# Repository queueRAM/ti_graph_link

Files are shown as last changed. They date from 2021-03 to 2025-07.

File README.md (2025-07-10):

TI-Graph Link adapters
----------------------
This repository contains information about three types of TI-Graph Link adapters:
* [TI-Graph Link serial (gray)](#ti-graph-link-serial-gray)
* [TI-Graph Link serial (black)](#ti-graph-link-serial-black)
* [TI USB Graph Link (silver)](#ti-usb-graph-link-silver)

Building Firmware
-----------------
The included makefile build system can build both the Silver Link "B" and the serial Gray Link firmware. The resulting .eep file should be bit-compatible with the EEPROM contents.

Silver Link build dependencies are:
 * [sdcc](http://sdcc.sourceforge.net): versions 3.8.0 through 4.2.0 have been tested
 * [GNU make](https://www.gnu.org/software/make/)
 * Python 3: for the script which generates the Autoexec header and checksum

Gray Link build dependencies are:
 * [gputils](https://gputils.sourceforge.io/): version 1.5.2 has been tested
 * [GNU make](https://www.gnu.org/software/make/)

```sh
$ make
sdas8051 -lops ti_graph_link_silver.asm
sdcc -mmcs51 --code-size 0x1400 ti_graph_link_silver.rel -o ti_graph_link_silver.hex
makebin -p ti_graph_link_silver.hex ti_graph_link_silver.bin
./tools/generate_eeprom.py ti_graph_link_silver.bin ti_graph_link_silver.eep
gpasm  -o ti_graph_link_serial_gray.hex ti_graph_link_serial_gray.asm
ti_graph_link_silver.bin: OK
ti_graph_link_serial_gray.hex: OK
```

TI-Graph Link serial (gray)
---------------------------
The gray TI-Graph Link cable uses a DB-25 serial connector and works with Windows and Macintosh computers. It includes adapters to connect to DB-9 RS232 serial port on a PC and a DIN adapter to connect to RS-422 serial port on a Mac. [Merthsoft's Link Cables page](http://merthsoft.com/linkguide/cable.html#greytigl) contains additional information about this cable.
TI-Graph Link serial gray
TI-Graph Link serial gray PCB annotated

## Gray Link: Schematic
Full schematic is included in the repository as [TI-Graph Link serial (gray) PDF](schematics/ti_graph_link_serial_gray/ti_graph_link_serial_gray_rev1.pdf) or KiCad.
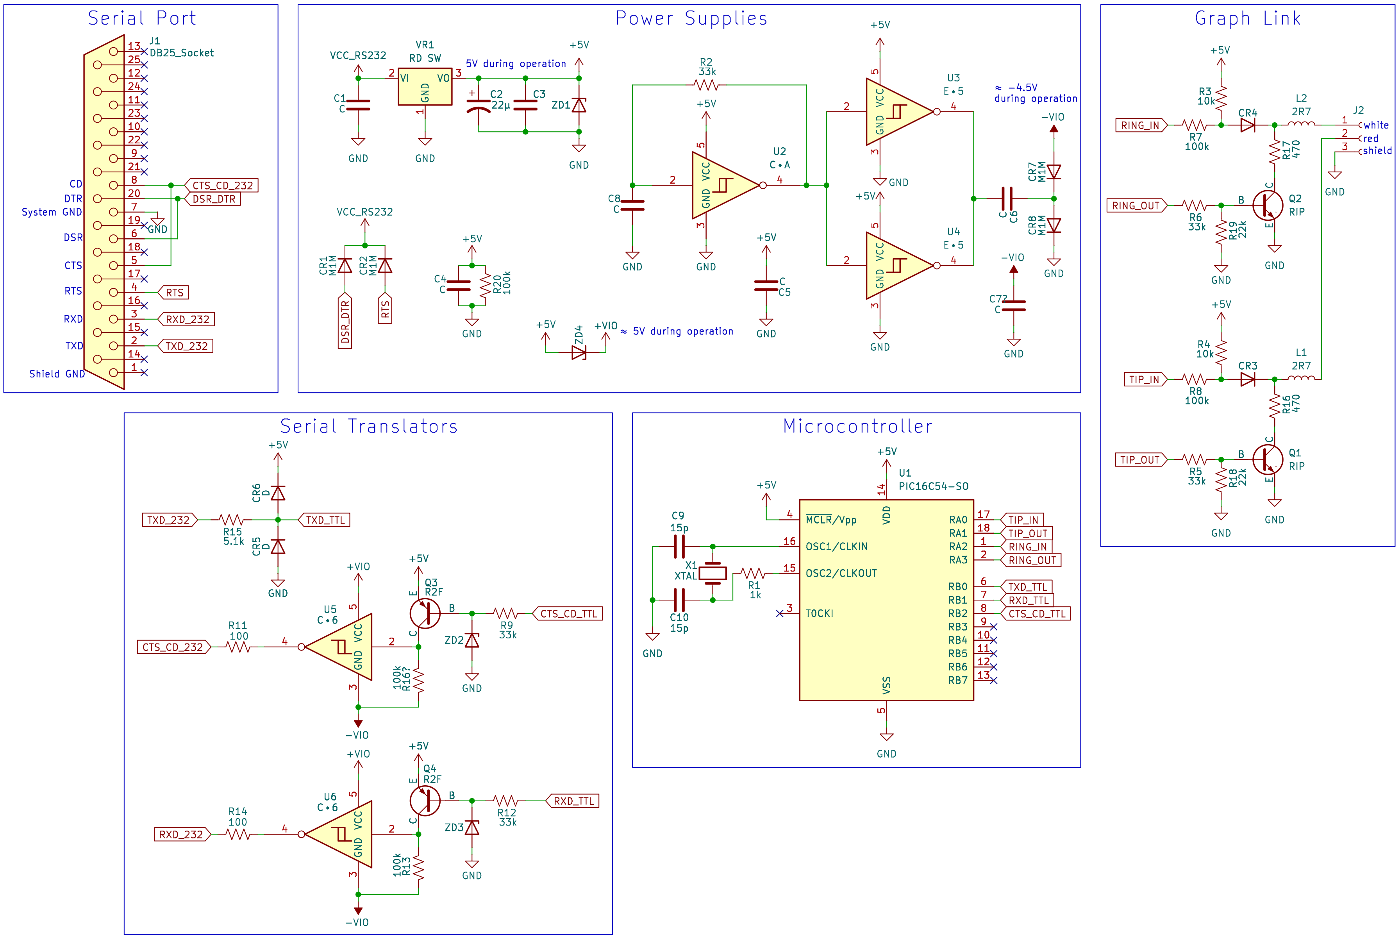
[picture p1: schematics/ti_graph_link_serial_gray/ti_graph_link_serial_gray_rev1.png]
TI-Graph Link serial (gray) Schematic


The control of the cable is provided with a PIC16C54 which receives requests on serial TX, sends responses back on serial RX, and manages the graph link communication on the tip/ring of the 2.5mm cable through two pairs of pins. There are three power supplies on board: 5V regulator for the PIC and graph-link communication and positive and negative voltages for the RS232 communication with the host.

### Gray Link: GPIO connectivity
Graph Link   | Direction | GPIO | IC Pin
-------------|-----------|------|-------
Tip (red)    | In        | RA0  | 17
Tip (red)    | Out       | RA1  | 18
Ring (white) | In        | RA2  | 1
Ring (white) | Out       | RA3  | 2

Notable parts:
* `U1`: PIC16C54
* `VR1`: 5V regulator, likely similar to TelCom TC55
* `CR3`/`CR4`: `M1M` diodes to supply power from RTS/DSR/DTR control lines
* `U2`, `U3`, `U4`, `U5`, `U6`: variants of Schmitt trigger inverter

TI-Graph Link serial (black)
----------------------------
The black serial Graph Link cable was the later revision with a female DB-9 connector and is only intended to work with Windows PCs.
TI-Graph Link serial black

TI-Graph Link serial black annotated PCB

## Black Link: Schematic
Full schematic is included in the repository as [TI-Graph Link serial (black) PDF](https://raw.githubusercontent.com/queueRAM/ti_graph_link/main/schematics/ti_graph_link_serial_black/ti_graph_link_serial_black_schematic_rev1.pdf) or KiCad.
TI-Graph Link serial (black) Schematic

* `CNTR`: connector for serial port control lines
* `CR3`/`CR4`: `M1M` diodes to supply power from RTS/DTR control lines
* `C1`/`C2`: bypass caps
* `U1`: [LM339AM](https://www.ti.com/lit/ds/symlink/lm339.pdf) single supply quad comparator
* `CR6`/`CR7`/`CR8`: diodes for inverting input and pullups
* `R6`/`R10`: pullups for inverting input and link port
* `R1`/`R2`/`R3`/`R4`/`R5`/`R7`/`R8`/`R9`: graph link circuitry around LM339
* `JACK`: 2.5mm 3-conductor graph link jack

TI USB Graph Link (Silver)
--------------------------

There are two hardware models of the Silver Graph Link USB cable: "A" and "B" as denoted by the last character of its production code. Most graph link cables contain a production code on the back label in the following format: `FMMYYH`:
 * `F` - Factory: `I` (Taiwan), `S` (China), `P` (China)
 * `MM` - Month of manufacture
 * `YY` - Year of manufacture
 * `H` - Hardware: either "A" or "B" (see description below)

The "A" version uses a Cypress CY7C64013 chipset and was manufactured from sometime in the early 2000s through March 2003. Starting around April 2003 through 2010, the "B" hardware version using the TI TUSB3410 was manufactured.

## Silver Link "A": Cypress CY7C64013

Some info about the "A" TI Silver Link is documented here: http://merthsoft.com/linkguide/usbdevices/SilverLink%20USB.txt
Silver Link "A" CY7C64013

### Silver Link "A": Schematic

Full schematic is included in the repository as ["A" Rev 1 PDF](https://raw.githubusercontent.com/queueRAM/ti_graph_link/main/schematics/ti_silver_link_a/ti_silver_link_a_rev1.pdf) or KiCad.
Silver Link "A" Schematic

* `D1`: `D3G` Rohm Schottky barrier diode [RB471E (PDF)](http://rohmfs.rohm.com/en/products/databook/datasheet/discrete/diode/schottky_barrier/rb471et148-e.pdf)
* `L4`, `L4`: `2R7` 2.7µH inductor
* `U1`: `DQF` Voltage Regulator, 3.3V [S-812XXSG (PDF)](http://www.sih.com.hk/sih_eng/products/ic/pdf/s812-e.pdf) (81233SGUP)
* `U2`: `H8` Rohm Bias resistor transistor [IMH8A (PDF)](http://rohmfs.rohm.com/en/products/databook/datasheet/discrete/transistor/digital/umh8ntr-e.pdf)
* `U3`: `CY7C64013` Cypress USB [CY7C64013,113 (PDF)](https://media.digikey.com/pdf/Data%20Sheets/Cypress%20PDFs/CY7C64013,113.pdf)
* `X1`: `6.0F2D` 6MHz Crystal

### Cypress CY7C64013

Cypress M8 Series (M8 Core w/ 8K EPROM)

The CY7C64013 is a Full-Speed USB microcontroller made by Cypress. It uses a 6MHz external clock source.
The CPU uses a proprietary 8-bit RISC M8 architecture and is clocked at 12MHz.

* [Cypress Website on CY7C64013](https://web.archive.org/web/20010405082135/http://www.cypress.com/cypress/prodgate/usb/cy7c64x13.htm)
* [Cypress Website about USB Programming Tools](https://web.archive.org/web/20010617083043/http://www.cypress.com/design/progprods/usb/usbprog.html)

### GPIO connectivity
Graph Link   | GPIO  | SOIC Pin
-------------|-------|---------
Tip (red)    | P0[0] | 17
Ring (white) | P0[1] | 13

## Silver Link "B": TI TUSB3410

Silver Link "B" TUSB3410

### Silver Link "B": Schematic
Full schematic is included in the repository as ["B" Rev 3 PDF](https://raw.githubusercontent.com/queueRAM/ti_graph_link/main/schematics/ti_silver_link_b/ti_silver_link_b_rev3.pdf) or KiCad.
TI Silver Graph Link "B" Schematic rev3

* `D1`: `D3G` Rohm dual Schottky barrier diode [RB471E (PDF)](http://rohmfs.rohm.com/en/products/databook/datasheet/discrete/diode/schottky_barrier/rb471et148-e.pdf)
* `D2`: `3F` Chenmko Schottky barrier diode [CH461FGP (PDF)](http://www.chenmko.com.tw/assets/uploaded_docs/1310112518k0vqy.pdf)
* `L1`, `L2`: `2R7` 2.7µH inductor
* `U1`: `24LC64` 64kbit EEPROM: Microchip [24LC64 (PDF)](https://ww1.microchip.com/downloads/en/DeviceDoc/21189T.pdf)
* `U2`: `AQI` TI LDO Regulator, 3.3V [TPS715 (PDF)](https://www.ti.com/lit/ds/symlink/tps715.pdf) (TPS71533DCKR)
* `U3`: `TUSB3410` USB TI [TUSB3410 (PDF)](https://www.ti.com/lit/ds/symlink/tusb3410.pdf)
* `U4`: `H8` Rohm Bias resistor transistor [IMH8A (PDF)](http://rohmfs.rohm.com/en/products/databook/datasheet/discrete/transistor/digital/umh8ntr-e.pdf)
* `Y1`: `12.0F4K` 12MHz Crystal

### GPIO connectivity
Graph Link   | GPIO | VQFN Pin
-------------|------|---------
Tip (red)    | P3.3 | 30
Ring (white) | P3.4 | 29

### EEPROM data

The EEPROM data contains a header which is first read by the bootloader in the TUSB3410 ROM. If the header matches the expected format, the size as is described in the header is read out from the EEPROM into Code RAM. The bootloader then jumps to this code.

#### Autoexec Binary Firmware:
OFFSET | TYPE                 | SIZE   | VALUE | DESCRIPTION
-------|----------------------|--------|-------|--------------------------
0x0000 | Signature0           | 1      | 0x10  | FUNCTION_PID_L
0x0001 | Signature1           | 1      | 0x34  | FUNCTION_PID_H
0x0002 | Data Type            | 1      | 0x07  | Autoexec binary firmware
0x0003 | Data Size(low byte)  | 1      | 0x00  | 0x1400 bytes of application code
0x0004 | Data Size(high byte) | 1      | 0x14  |
0x0005 | Check Sum            | 1      | 0x5a  | Checksum of the following firmware
0x0006 | Program              | 0x1400 |       | Binary application code
0x1406 | Data Type            | 1      | 0x00  | End of header

### Silver Link "B": Firmware
TUSB3410 contains an 8052 microprocessor. The application code contained within the EEPROM
is responsible for receiving commands over USB and communicating with the calculator over its
PORT3 GPIO.

TI USB Graph Link Breadboard Edition
------------------------------------

User ["okrayo" on the Cemetech forums](https://www.cemetech.net/forum/viewtopic.php?p=302975#302975) recreated the TI USB Graph Link "B" on a breadboard using a TUSB3410 and through-hole alternatives for the power supply, transistors, diodes, and passive components. Since this uses the same USB chipset and firmware as the official Silver USB Graph-Link, this works with existing SW and TI graphing calculators with 2.5mm data port.

TI USB Graph Link Breadboard Edition

## Component Replacements

The table below enumerates the part replacements that "okrayo" used in the design relative to the original "B" schematic. In addition to these parts, the following modifications were made:
 - Added 0.1µF decoupling capacitor between 1V8 and GND
 - Removed the `L2`/`C9` `L1`/`C10` filter on tip and ring connections
 - Added LED + 330Ω resistor on 3V3
 - Left 24LC256 `WP` pin disconnected to prevent inadvertent writes

RefDes  | Description          | "B" Part    | Breadboard Part
--------|----------------------|-------------|------------------
C1/C5   | Xtal caps            | 33pF SMT    | 22pF through-hole
D2      | Suspend Diode        | CH461FGP    | [1N4148](https://en.wikipedia.org/wiki/1N4148_signal_diode)
R8/R9   | USB D+/D- Res.       | 22Ω         | 27Ω
R20/R21 | 1V8 voltage divider  | 90.5k/100kΩ | 15k/18kΩ
R24     | VREGEN Resistor      | 32.4kΩ      | 33kΩ
U2      | 3.3V volt. regulator | TPS71533    | [MCP17003302E](https://www.microchip.com/en-us/product/MCP1700)
U4      | Transistors          | IMH8A       | 2x [PN2222A](https://www.onsemi.com/pdf/datasheet/p2n2222a-d.pdf)
U1      | EEPROM               | 24LC64      | [24LC256](https://www.microchip.com/en-us/product/24LC256)
D1      | Schottky Diodes      | RB471E      | 2x [MBR150](https://www.onsemi.com/pdf/datasheet/mbr150-d.pdf)

## TI USB Graph Link Breadboard Edition: Schematic

Full schematic is included in the repository as [TI Graph-Link "okrayo" Breadboard PDF](https://raw.githubusercontent.com/queueRAM/ti_graph_link/main/schematics/ti_silver_link_breadboard/ti_silver_link_okrayo_breadboard_rev3.pdf) or KiCad.
TI Graph Link "okrayo" Breadboard Schematic rev3

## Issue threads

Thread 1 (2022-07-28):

Hash missing

TheDatadrainer, 2022-07-28:
Hi.
I have a problem with my old TI-Graph Link as it is recognized as a TUSB3410 Boot Device. As this chip have this descriptor embedded in ROM and used it if the bootloader does not find a matching USB data or I²C ROM, and as the TUSB3410 seems to be working fine, my first suspect is the 24LC64. I desoldered it and I made a dump.
Then I compiled your source. And by comparing the two files (my bin and the ti_graph_link_silver.eep compiled from your source) I see a difference in the area 0x10002 to 0x1100E. Do you have any idea why?
Can you please put the ti_graph_link_silver.sha1 in your repo so that is it can be used to check the build validity. Thank you very much for that :) It will help confirm my dump is corrupted somehow.

What is strange is that except that area, the rest of the data is the same, which mean depending of what this area of data is doing the problem can be elsewhere in the circuit... But I don't know where, the TPS715 is okay, so are the resistors. If you have any idea, I'm taking it! Thanks for your help.

Regards

queueRAM, 2022-07-29:
Thanks for letting me know about the missing sha1 file!

> I see a difference in the area 0x10002 to 0x1100E. Do you have any idea why?

What do you mean by these offsets? My dump is only 0x1400 bytes long. Note that I didn't dump the full EEPROM, only probed the bus during the TUSB3410's boot sequence FW transfer.

TheDatadrainer, 2022-07-29:
Thank you for answer and for the the sha1 file.
Whoops, I put an extra zero, just see that. The area with different data is at offset 0x1002 to 0x110E (8KB ROM anyway). My mistake.
Maybe I have a different version of the firmware. I have dumped the ROM several time with the same output each time.
If you want I can sent it to you. I'm not an electronics engineer but for what I understand this circuit (version B) is quite simple in its design. I have another cable but I would like to understand what happened with this one, as it can happen again. And I don't like to trash things if they can be fixed!
The 24LC64 is driven by the TUSB3410 at 400 KHz and is forced read only because WP is hardwired to VSS. So no possible writing or desync.
I checked the traces around both chips and no problem here. With or without the EEPROM, the cable is detected as a TUSB3410 Boot Device with no problem. When using TI development driver, data can be sent. That's what make me think the TUSB3410 is working fine. I checked all the resistors around and their values are correct (none burned). So if the EEPROM is working fine too where the problem can be? That's bugging me...
As you have make an extensive work on this cable, I hope you can give me clues. Thank you very very much in advance.
Kind regards.

queueRAM, 2022-07-30:
If only the area 0x1002 to 0x110E is different, then it sounds like you have a corrupted EEPROM. There is a checksum in the header at offset 0x05 which covers the entire 0x1400 binary (0x0006-0x1405). Therefore if you have any bytes different in that range, then byte 0x05 should also differ. I suspect corrupted EEPROM and this is causing the checksum to fail and the application to not load. I've dumped the EEPROM from several different revisions of the "B" Silver Link and they have all been the same. That said, I would be interested in seeing your EEPROM dump.

If you want to see specifically what the data should look like, I annotated much of the [asm file](https://github.com/queueRAM/ti_graph_link/blob/main/ti_graph_link_silver.asm#L3031-L3050). The offsets here are relative to the application binary (so 0x0000 in the asm is 0x0006 in the EEPROM). Therefore, 0x1002 is in the `Manufacturer String` section:
```
00000ff0: 0354 0065 0078 0061 0073 0020 0049 006e  .T.e.x.a.s. .I.n
00001000: 0073 0074 0072 0075 006d 0065 006e 0074  .s.t.r.u.m.e.n.t
00001010: 0073 0024 0354 0049 002d 0047 0052 0041  .s.$.T.I.-.G.R.A
00001020: 0050 0048 0020 004c 0049 004e 004b 0020  .P.H. .L.I.N.K.
00001030: 0055 0053 0042 0041 81ff ff00 0000 00cf  .U.S.B.A........
```

TheDatadrainer, 2022-08-01:
Did you get my emails where I explained the problem is solved by dumping your firmware?
I replied from my email client because I have joined photos, but I don't know if GitHub allow this...

queueRAM, 2022-08-01:
No, I have not received any emails from you. I think if you reply to this GitHub notification in email it will just go to some throwaway address. You can find my email address in the git repo commits, reach out to me on Discord, or PM me on [Cemetech](https://www.cemetech.net/forum/profile.php?mode=viewprofile&u=34762)

Closed 2022-07-29.

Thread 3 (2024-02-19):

+3.3V and +3V3 nets in Silver Link "B" schematic

izero79, 2024-02-19:
Hi,

I started to draw a pcb for the Silver Link B Rev 2 schematic and noticed that there is net for +3.3V and +3V3. I guess these should be the same net, or is there something that I didn't understand?

Do you have values for the lc filter caps, C9 & C10?

Also not related question, but do you have measurements for the original board? I could make the pcb so that it would fit in the original case (if someone would need that) if you can provide the dimensions as in the attached pic.

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

queueRAM, 2024-02-25:
Good catch on the +3.3V and +3V3. They are in fact supposed to be the same net and I'll change them all to +3V3

> Do you have values for the lc filter caps, C9 & C10?

I do not know C9 and C10 values since they are unlabeled and I'm not actually sure how to measure them in circuit. Any recommendations?

> Also not related question, but do you have measurements for the original board?

I just took these with a caliper. x&y are fairly precise, may want to use pixel dimensions of picture to confirm the rest
a = 2.45mm (0.096in) - difficult to measure
b = 1.11mm (0.043in) - difficult to measure, might be better to constrain with "x-(b+c)" below
c = 7.59mm (0.298in)
d = 2.13mm (0.084in) - assuming hole diameter
e = 24.72mm (0.973in) - difficult get hole center
x = 65.32mm (2.571in)
y = 18.24mm (0.718in)
x-(b+c) = 56.21mm (2.213in)

izero79, 2024-02-26:
Thanks, can't say is there a reliable way to measure the caps in circuit. I need to study that what the values could be in that use case and try it out.

Measurements are more than precise enough. I will do a board drawing in near future and maybe I can make a pull request if you want to include that. Thank you again.

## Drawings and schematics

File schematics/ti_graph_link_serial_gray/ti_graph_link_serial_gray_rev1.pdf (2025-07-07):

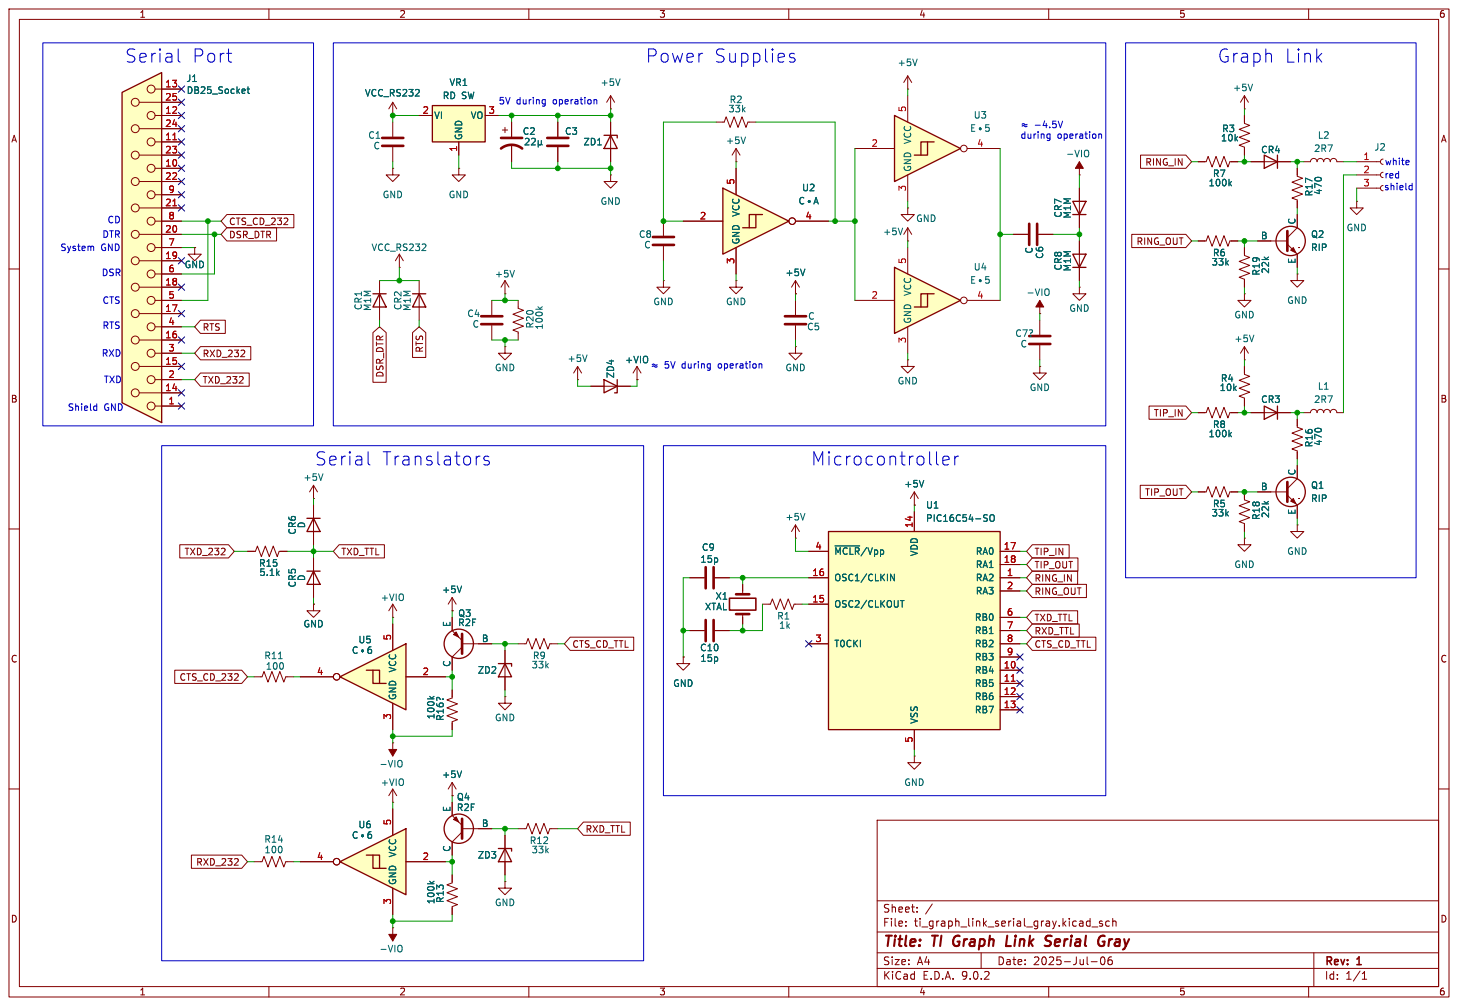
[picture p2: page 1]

File: ti_graph_link_serial_gray.kicad_sch Sheet: /
Id: 1/1 Title: TI Graph Link Serial Gray

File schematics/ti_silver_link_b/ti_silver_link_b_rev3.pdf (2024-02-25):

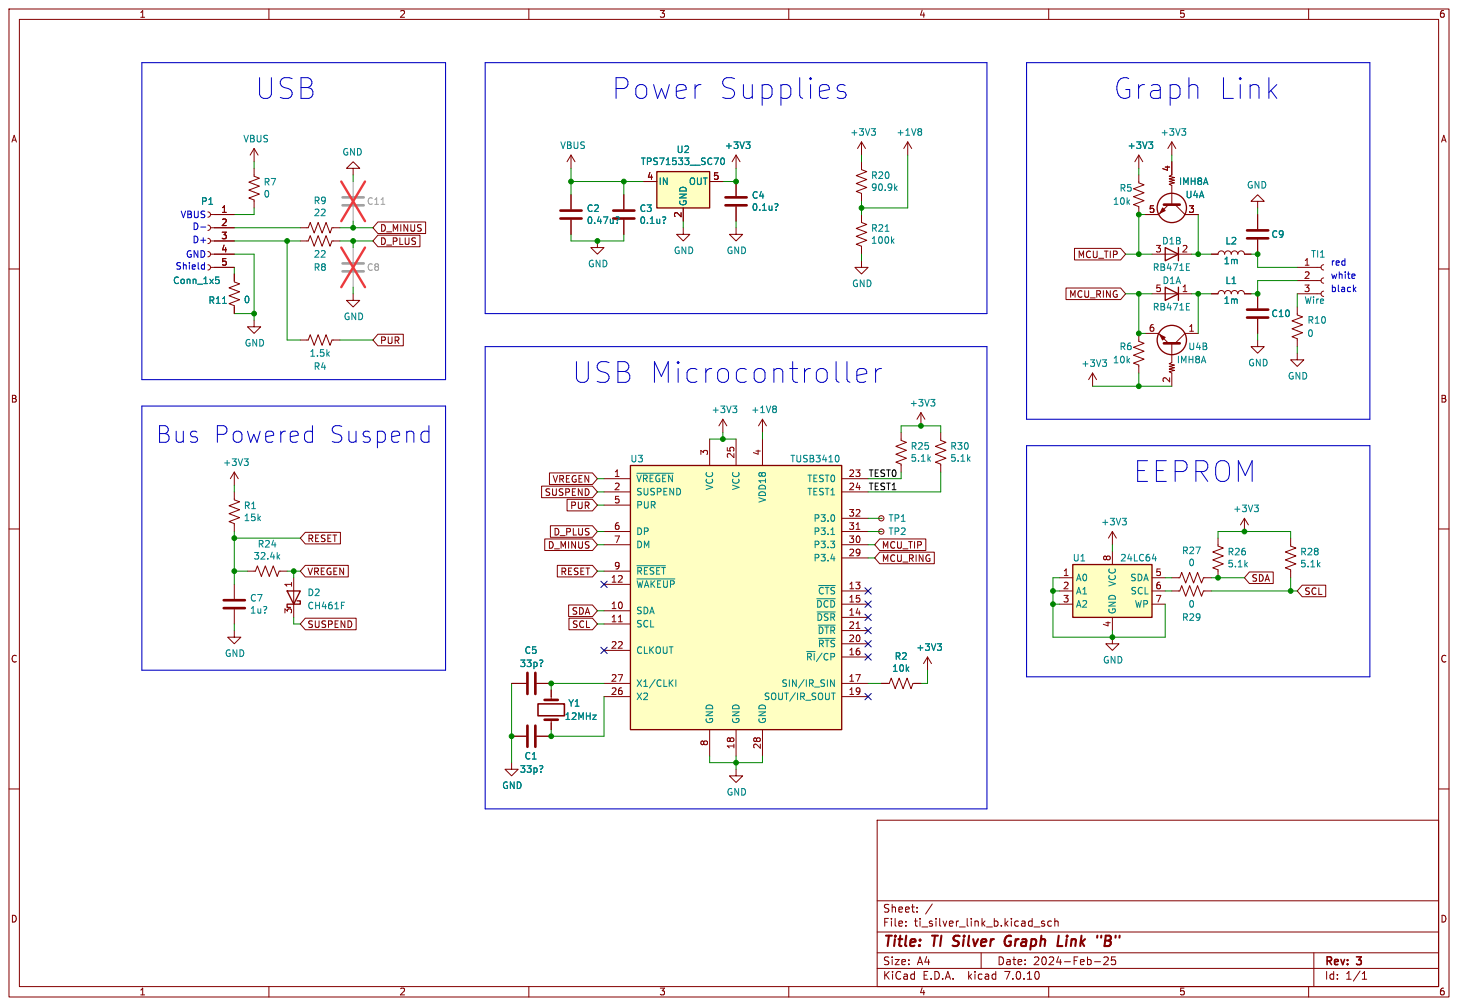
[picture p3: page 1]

1 3 D2 CH461F GND GND GND GND

4 PUR 5 DP 6 DM 7 GND

4 SDA 5 SCL 6 WP 7 VCC

File: ti_silver_link_b.kicad_sch Sheet: /
Id: 1/1 Title: TI Silver Graph Link "B"

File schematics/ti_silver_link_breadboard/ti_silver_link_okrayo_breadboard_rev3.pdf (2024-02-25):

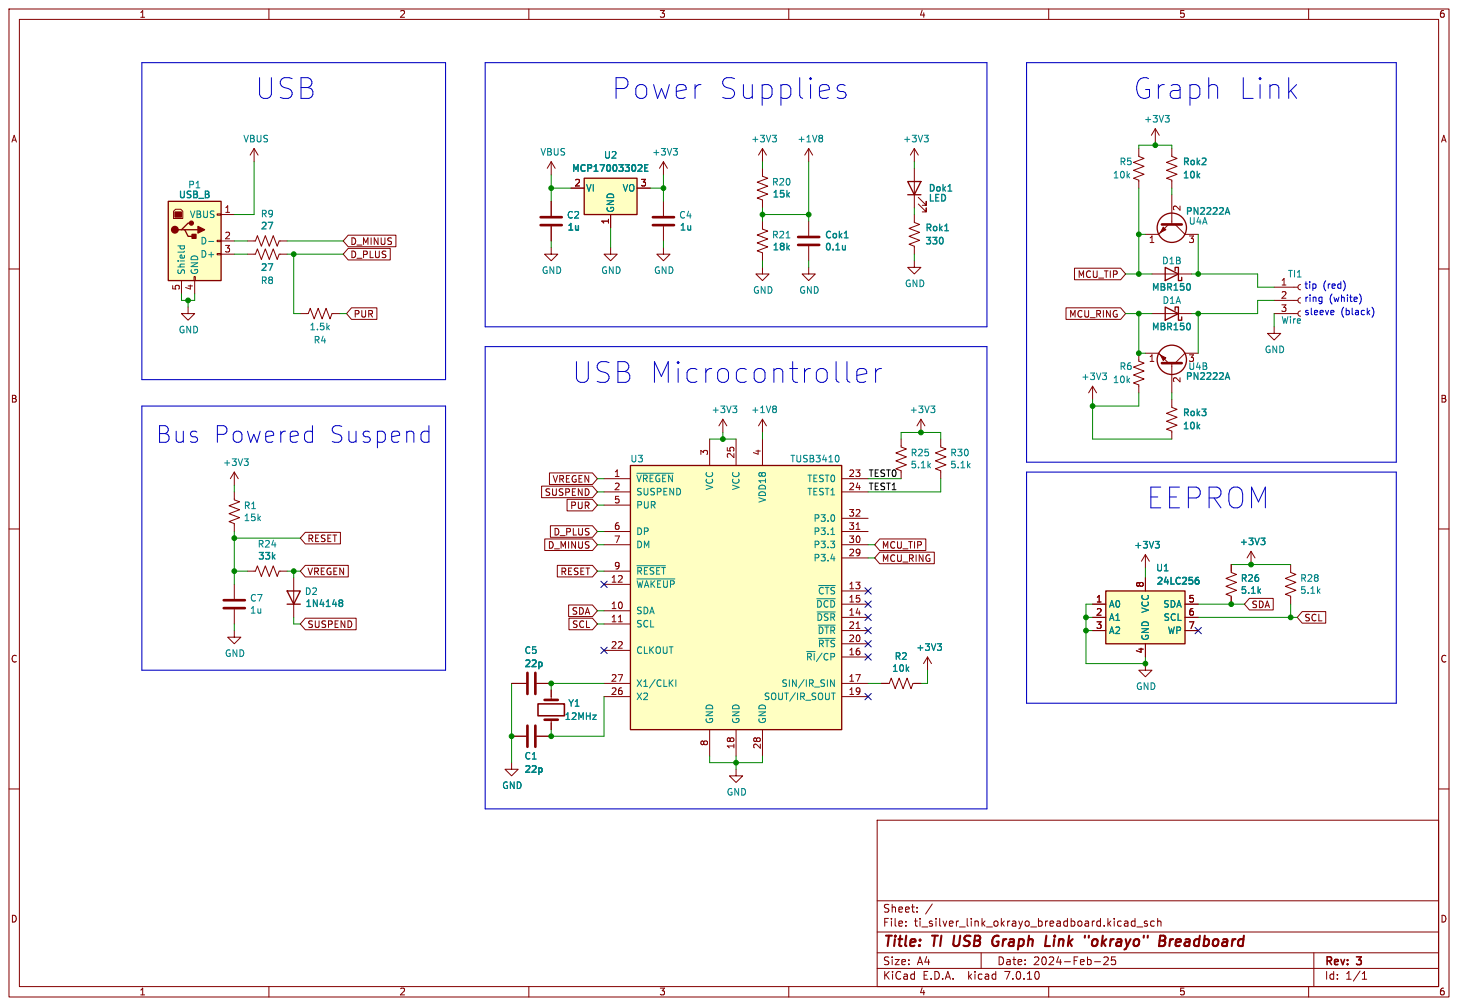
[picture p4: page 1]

4 PUR 5 DP 6 DM 7 GND

4 SDA 5 SCL 6 WP 7 VCC

File: ti_silver_link_okrayo_breadboard.kicad_sch Sheet: /
Id: 1/1 Title: TI USB Graph Link "okrayo" Breadboard

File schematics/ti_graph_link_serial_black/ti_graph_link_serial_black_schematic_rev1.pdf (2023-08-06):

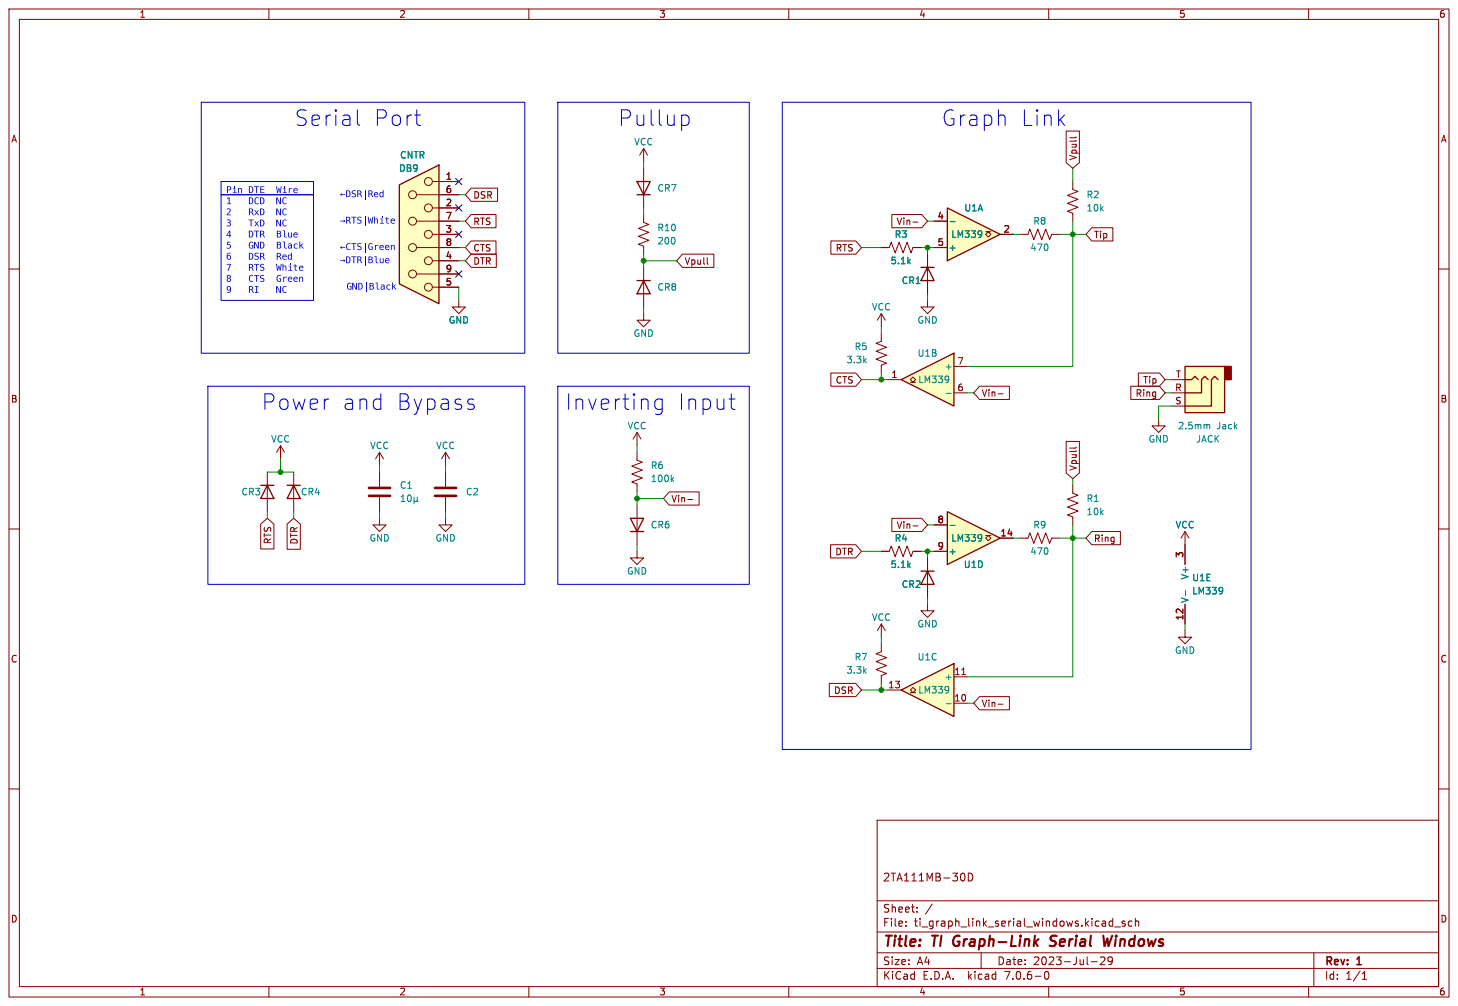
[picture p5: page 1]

þÿ!’DTR|Blue Pin DTE Wire

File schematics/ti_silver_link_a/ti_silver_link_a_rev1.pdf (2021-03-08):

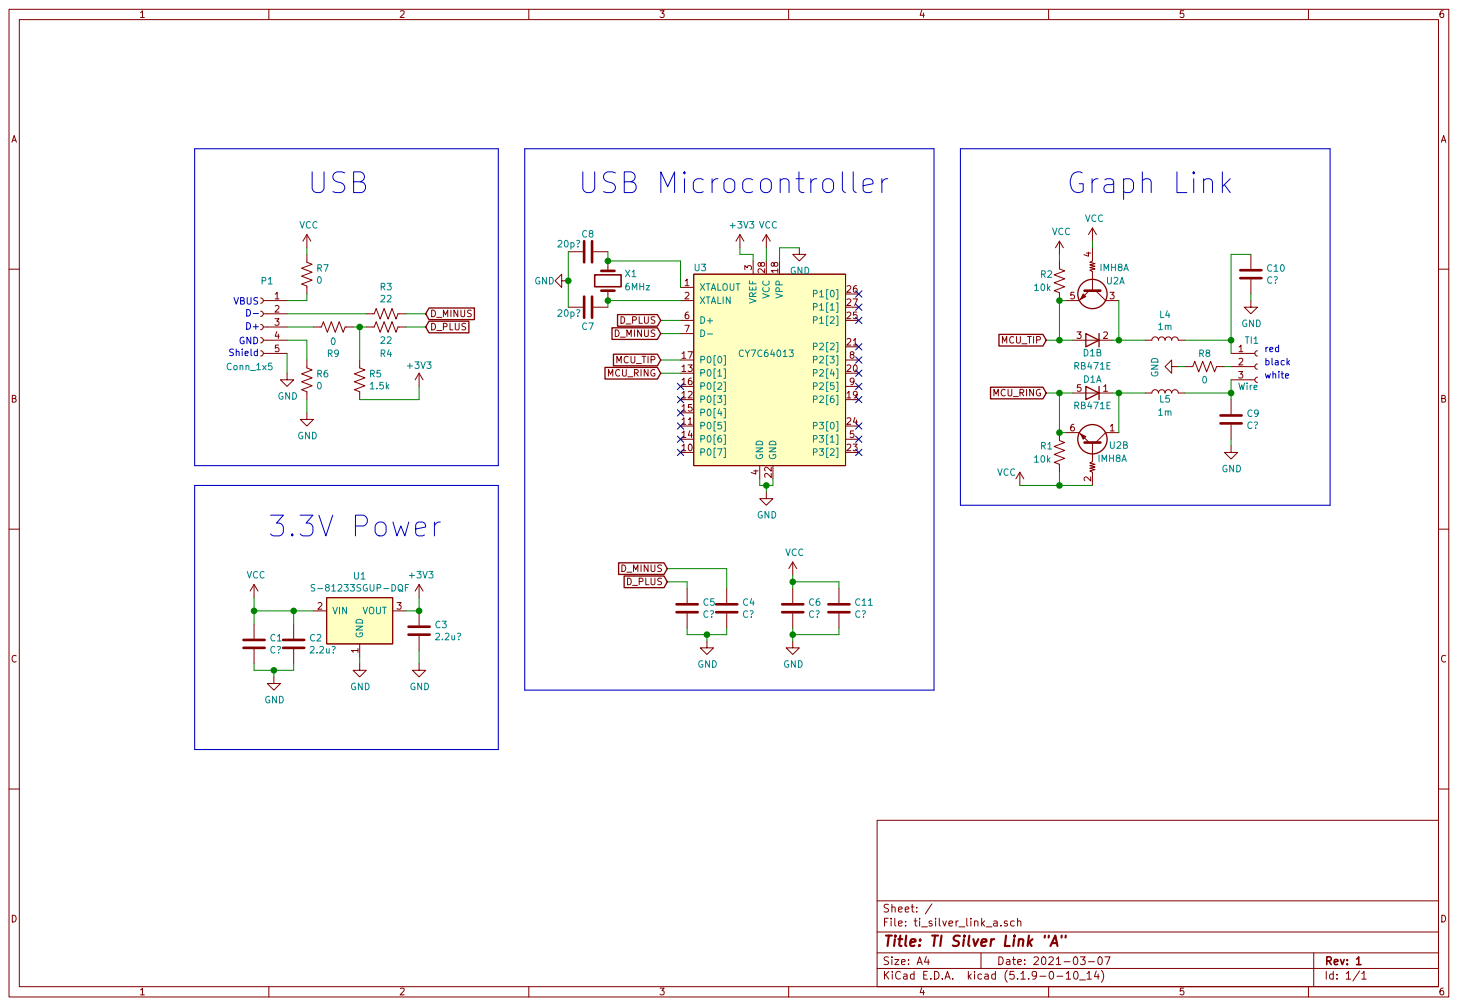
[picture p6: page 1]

File: ti_silver_link_a.sch Sheet: / GND

1 VIN 2 VOUT 3 U1 S-81233SGUP-DQF GND

Id: 1/1 Title: TI Silver Link "A"

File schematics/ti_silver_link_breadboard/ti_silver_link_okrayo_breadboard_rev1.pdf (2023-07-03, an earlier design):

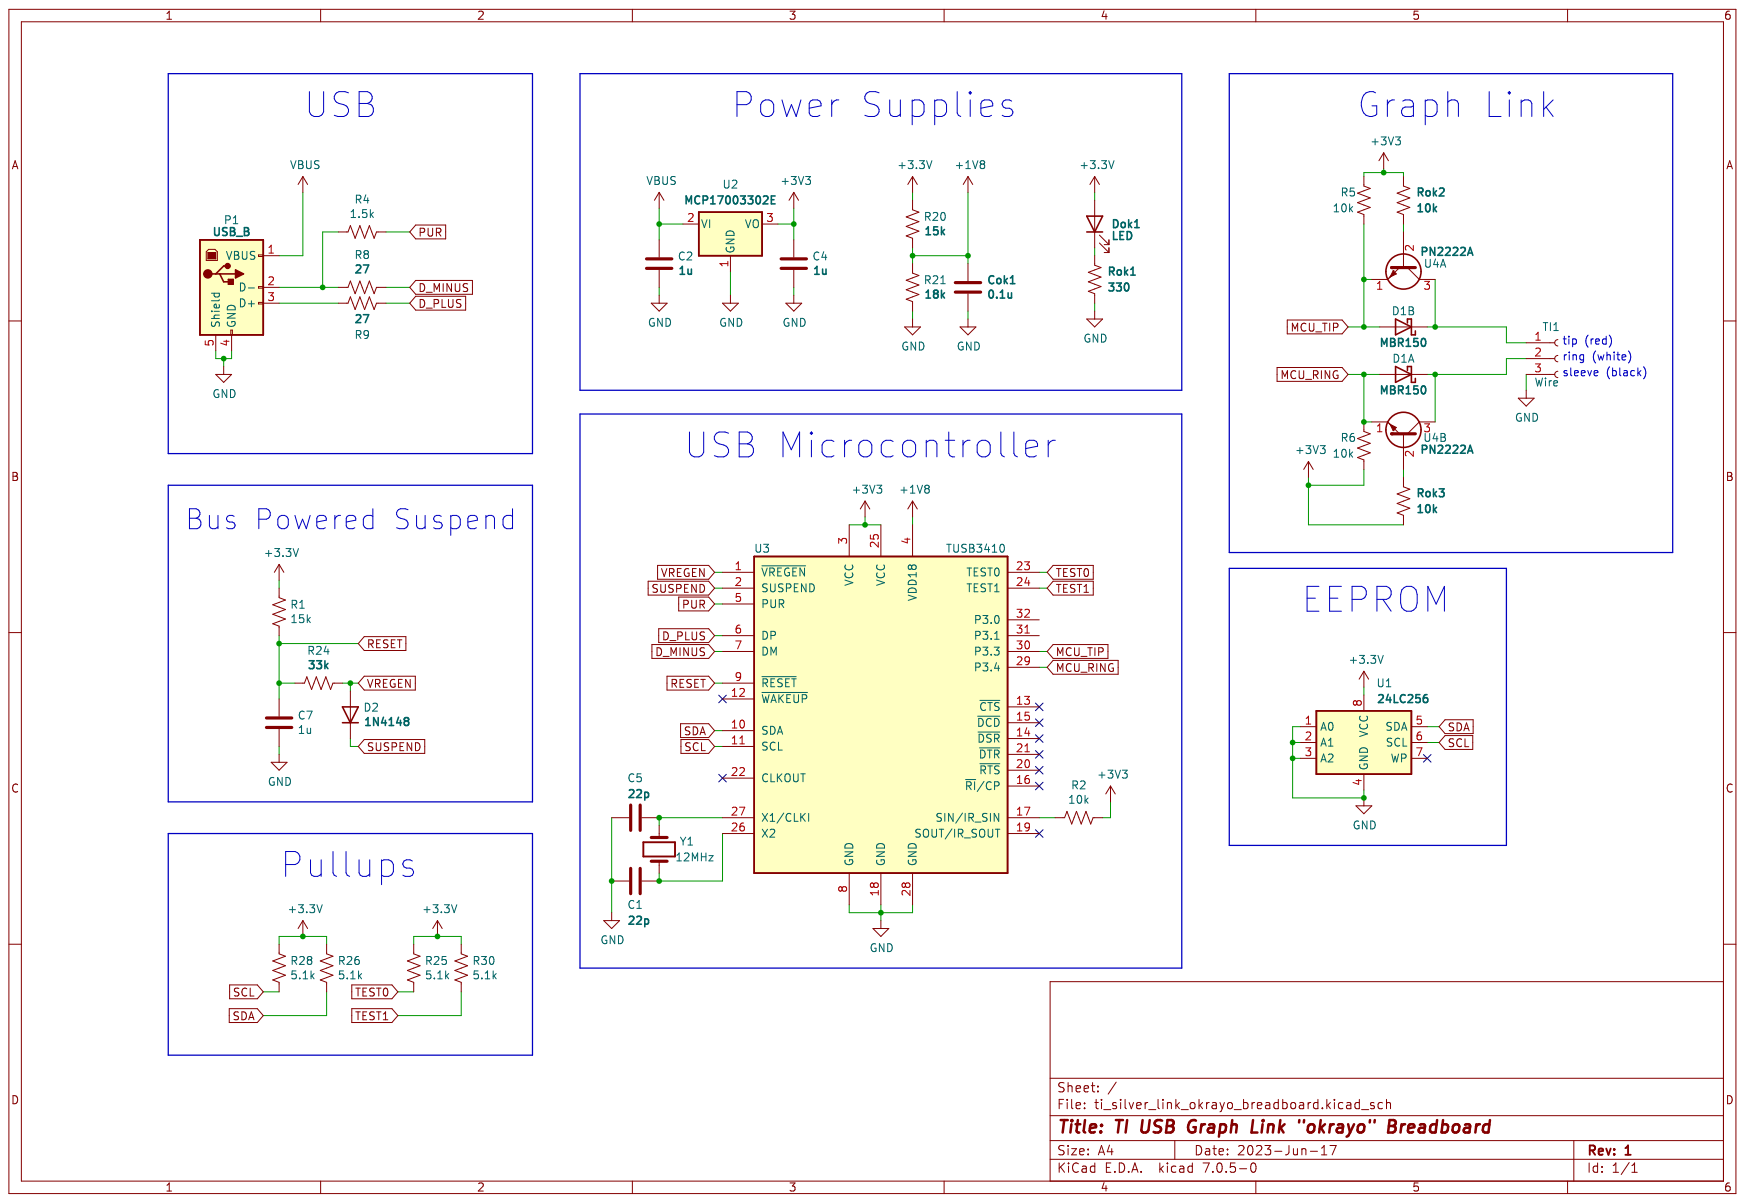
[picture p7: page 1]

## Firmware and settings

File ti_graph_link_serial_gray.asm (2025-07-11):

; assemble with gputils:
; $ gpasm -o ti_graph_link_serial_gray.hex ti_graph_link_serial_gray.asm

    processor 16C54
    #include <P16C5x.INC>
    __config _CP_OFF & _WDT_ON & _XT_OSC ; 0x0FFD
    __idlocs 0xC830

; RAM variables
StateFlags equ 0x07 ; flags, bits 0-5 are used
LRAM_0x08 equ 0x08 ; stores incoming serial bits from TX
LRAM_0x09 equ 0x09 ; stores count of remaining bits
LRAM_0x0A equ 0x0A ; stores the bits sending out GraphLink
LRAM_0x0B equ 0x0B ; stores count of remaining bits
JumpBack equ 0x0C ; used as destination PC
LRAM_0x0D equ 0x0D ; counter for something
LRAM_0x0E equ 0x0E ; likely pointer, stored to FSR
LRAM_0x0F equ 0x0F ; likely pointer, stored to FSR

; Graph-Link pins
#define TIP_in   PORTA,0
#define TIP_out  PORTA,1
#define RING_in  PORTA,2
#define RING_out PORTA,3

; RS232 pins
#define Ser_TX   PORTB,0
#define Ser_RX   PORTB,1
#define Ser_CTS  PORTB,2

; debug
#define DebugPin PORTB,7

    ; Program
    Org 0x0000

; waits for either tip or ring to be pulled low or timeout
LADR_0x0000:
    BTFSC TIP_in         ; if TIP == 0 || RING == 0:
      BTFSS RING_in
        GOTO LADR_0x0006 ;   GOTO LADR_0x0006
    BTFSC TMR0,7         ; if TMR0[7] == 1:
      GOTO LADR_0x00E7   ;   GOTO LADR_0x00E7
    GOTO LADR_0x0000

LADR_0x0006:
    BTFSC StateFlags,5   ; if StateFlags[5] == 1:
      GOTO LADR_0x00E5   ;   GOTO LADR_0x00E5

    BSF StateFlags,3     ; StateFlags[3] = 1
    MOVLW 0x08           ; LRAM_0x0B = 0x08
    MOVWF LRAM_0x0B
LADR_0x000B:
    MOVLW LADR_0x000F    ; JumpBack = LADR_0x000F
    MOVWF JumpBack
LADR_0x000D:
    BTFSC TMR0,7         ; if TMR0[7] == 1:
      GOTO LADR_0x00E7   ;   GOTO LADR_0x00E7
LADR_0x000F:
    BTFSS RING_in        ; if RING == 0:
      GOTO LADR_0x0036   ;   GOTO LADR_0x0036

    BTFSC TIP_in         ; if TIP == 1:
      GOTO LADR_0x000D   ;   GOTO LADR_0x000D

    BTFSS RING_in        ; if RING == 0:
      GOTO LADR_0x0116   ;   GOTO LADR_0x0116

    RRF LRAM_0x0A,F      ; LRAM_0x0A = LRAM_0x0A >> 1
    BCF LRAM_0x0A,7
    BSF RING_out         ; RING = 1

    MOVLW LADR_0x001C    ; JumpBack = LADR_0x001C
    MOVWF JumpBack

LADR_0x001A:
    BTFSC TMR0,7         ; if TMR0[7] == 1:
      GOTO LADR_0x00E7   ;   GOTO LADSR_0x00E7

LADR_0x001C:
    BTFSS TIP_in         ; if TIP == 0:
      GOTO LADR_0x001A   ;   GOTO LADR_0x001A

    BCF RING_out         ; RING = 0

    MOVLW LADR_0x0025    ; JumpBack = LADR_0x0025
    MOVWF JumpBack

; wait until RING is high or timeout
LADR_0x0021:
    BTFSC TMR0,7         ; if TMR0[7] == 1:
      GOTO LADR_0x00E7   ;   GOTO LADR_0x00E7
    BTFSS RING_in        ; if RING == 0:
      GOTO LADR_0x0021   ;   GOTO LADR_0x0021

LADR_0x0025:
    DECFSZ LRAM_0x0B,F   ; LRAM_0x0B -= 1
      GOTO LADR_0x000B   ; if LRAM_0x0B != 0: GOTO LADR_0x000B

    MOVF LRAM_0x0E,W     ; W = LRAM_0x0E
    IORLW 0xF0           ; W |= 0xF0
    MOVWF FSR            ; FSR = W

    MOVF LRAM_0x0A,W     ; W = LRAM_0x0A
    MOVWF INDF           ; IND = W

    INCF LRAM_0x0E,F     ; LRAM_0x0E += 1
    INCF LRAM_0x0D,F     ; LRAM_0x0D += 1

    BTFSC LRAM_0x0D,4    ; if LRAM_0x0D[4] == 1:
      BSF StateFlags,5   ;   StateFlags[5] = 1

    BCF StateFlags,4     ; StateFlags[4] = 0
    BCF StateFlags,3     ; StateFlags[3] = 0

    MOVLW LADR_0x0000    ; JumpBack = LADR_0x0000
    MOVWF JumpBack

    CLRWDT               ; reset watchdog
    GOTO LADR_0x00E5

LADR_0x0036:
    BTFSS TIP_in         ; if TIP == 0:
      GOTO LADR_0x0116   ;   GOTO LADR_0x0116

    RRF LRAM_0x0A,F      ; LRAM_0x0A = (LRAM_0x0A >> 1) | 0'b1000_0000
    BSF LRAM_0x0A,7
    BSF TIP_out          ; TIP = 1
    MOVLW LADR_0x003F    ; JumpBack = LADR_0x003F
    MOVWF JumpBack

    ; loop until RING goes high or timeout
LADR_0x003D:
    BTFSC TMR0,7         ; if TMR0[7] == 1:
      GOTO LADR_0x00E7   ;   GOTO LADR_0x00E7
LADR_0x003F:
    BTFSS RING_in        ; if RING == 0:
      GOTO LADR_0x003D   ;   GOTO LADR_0x003D

    BCF TIP_out          ; TIP = 0
    MOVLW LADR_0x0048    ; JumpBack = LADR_0x0048
    MOVWF JumpBack

    ; loop until TIP goes low or timeout
LADR_0x0044:
    BTFSC TMR0,7         ; if TMR0[7] == 1:
      GOTO LADR_0x00E7   ;   GOTO LADR_0x00E7
    BTFSS TIP_in         ; if TIP == 0:
      GOTO LADR_0x0044   ;   GOTO LADR_0x0044

LADR_0x0048:             ; mostly a copy of the code from LADR_0x0025
    DECFSZ LRAM_0x0B,F   ; LRAM_0x0B -= 1
      GOTO LADR_0x000B   ; if LRAM_0x0B != 0: GOTO LADR_0x000B

    MOVF LRAM_0x0E,W     ; FSR = LRAM_0x0E | 0xF0
    IORLW 0xF0
    MOVWF FSR

    MOVF LRAM_0x0A,W     ; INDF = LRAM_0x0A
    MOVWF INDF

    INCF LRAM_0x0E,F     ; LRAM_0x0E += 1
    INCF LRAM_0x0D,F     ; LRAM_0x0D += 1

    BTFSC LRAM_0x0D,4    ; if LRAM_0x0D[4] == 1:
      BSF StateFlags,5   ;   StateFlags[5] = 1

    BCF StateFlags,4     ; StateFlags[4] = 0
    BCF StateFlags,3     ; StateFlags[3] = 0

    MOVLW LADR_0x0000    ; JumpBack = LADR_0x0000
    MOVWF JumpBack

    CLRWDT               ; reset watchdog
    GOTO LADR_0x00E5

LADR_0x0059:
    BTFSC StateFlags,4   ; if StateFlags[4] == 1:
      GOTO LADR_0x00F6   ;   GOTO LADR_0x00F6

    BSF StateFlags,3     ; StateFlags[3] = 1
    MOVLW 0x08           ; LRAM_0x0B = 0x08
    MOVWF LRAM_0x0B

    MOVF LRAM_0x0F,W     ; FSR = LRAM_0x0F | 0xF0
    IORLW 0xF0
    MOVWF FSR

    MOVF INDF,W          ; LRAM_0x0A = INDF
    MOVWF LRAM_0x0A

    INCF LRAM_0x0F,F     ; LRAM_0x0F += 1
    DECF LRAM_0x0D,F     ; LRAM_0x0D -= 1
    BTFSC STATUS,Z       ; if LRAM_0x0D == 0:
      BSF StateFlags,4   ;   StateFlags[4] = 1

    BCF StateFlags,5     ; StateFlags[5] = 0
    MOVF LRAM_0x0D,W     ; W = LRAM_0x0D
    XORLW 0x0F           ; W = W ^ 0x0F
    BTFSC STATUS,Z       ; if STATUS.Z == 1 (W == 0):
      GOTO LADR_0x0071   ;   GOTO LADR_0x0071

    MOVF LRAM_0x0D,W     ; W = LRAM_0x0D
    XORLW 0x0E           ; W = W ^ 0x0E
    BTFSC STATUS,Z       ; if STATUS.Z == 0 || StateFlags[0] == 0:
      BTFSS StateFlags,0
        BCF Ser_CTS      ; CTS = 0
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

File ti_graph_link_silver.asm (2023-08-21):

; Disassembly of TI silver Graph Link program data extracted from
; EEPROM connected to TUSB3410

; TUSB3410 contains 8052 microprocessor. The bootloader in ROM will
; Extract verify valid signature and program header and copy the program
; contents from EEPROM to RAM.

; Build with sdcc toolchain:
; $ make
; sdas8051 -lops ti_graph_link_silver.asm
; sdcc -mmcs51 --code-size 0x1400 ti_graph_link_silver.rel -o ti_graph_link_silver.hex
; makebin -p ti_graph_link_silver.hex ti_graph_link_silver.bin

; definitions of registers
OEPCNF_2   = 0xff10
OEPBBAX_2  = 0xff11
OEPBCTX_2  = 0xff12
OEPSIZXY_2 = 0xff17

IEPCNF_1   = 0xff48
IEPBBAX_1  = 0xff49
IEPBCTX_1  = 0xff4a
IEPSIZXY_1 = 0xff4f

IEPCNFG_0 = 0xff80
IEPBCNT_0 = 0xff81
OEPCNFG_0 = 0xff82
OEPBCNT_0 = 0xff83

WDCSR  = 0xff93
VECINT = 0xff92

I2CSTA  = 0xfff0
I2CDATO = 0xfff1
I2CADR  = 0xfff3

USBCTL = 0xfffc
USBMSK = 0xfffd
USBSTA = 0xfffe
FUNADR = 0xffff

.area PSEG    (PAG,XDATA)

;--------------------------------------------------------
; data
;--------------------------------------------------------
.area DSEG    (DATA)

  .word 0, 0, 0, 0, 0, 0, 0, 0
  .word 0, 0, 0, 0, 0, 0, 0, 0

dat_20_start:
dat_20_end:

i2c_addr: ; 0x20
  .byte 0

dat_21:
  .byte 0

eeprom_addr:
  .word 0

dat_24:
  .word 0

dat_26:
  .byte 0
dat_27:   ; TODO: sometimes this is word, sometimes byte?
  .word 0

  .byte 0, 0, 0, 0, 0, 0, 0

  .word 0, 0, 0, 0, 0
  .byte 0

bss_start:
i2c_speed: ; 0x3b
  .byte 0

  .word 0

dat_3e:
  .word 0

  .word 0, 0, 0
  .byte 0

dat_47:
  .byte 0

  .byte 0, 0, 0, 0, 0, 0

dat_4e:
  .byte 0

  .byte 0, 0, 0, 0

dat_53:
  .byte 0
  .byte 0, 0, 0, 0, 0

dat_59:
  .byte 0

dat_5a:
  .byte 0

dat_5b:
  .byte 0

dat_5c:
  .byte 0

dat_5d:
  .byte 0

  .byte 0, 0, 0, 0
bss_end:

data_start:
dat_62:
  .word 0

dat_64:
  .byte 0

dat_65:
  .byte 0

  .byte 0, 0

dat_68:
  .byte 0
data_end:

stack_start:

;--------------------------------------------------------
; xdata
;--------------------------------------------------------
.area XSEG    (XDATA)

xdat_0001:

;--------------------------------------------------------
; code
;--------------------------------------------------------
.area HOME    (CODE)

; interrupt vector @ 0x0000
int_vec:
  ljmp  reset_isr  ; 0x0000: Reset
  ljmp  exti_isr   ; 0x0003: External Interrupt 0
  nop
  nop
  nop
  nop
  nop
  ljmp  timer0_isr ; 0x000b: Timer-0 Interrupt

;--------------------------------------------------------
; code
;--------------------------------------------------------
.area CSEG    (CODE)

reset_isr: ; 0x000e
  mov   sp, #stack_start-1
  lcall fcn_02c9
  mov   a, r4
  orl   a, r5
  jz    lbl_0082
  mov   r0, #bss_end-1
  sjmp  lbl_001f
lbl_001c:
  mov   @r0, #0x00
  dec   r0
lbl_001f:
  cjne  r0, #bss_start, lbl_001c
  mov   r0, #0x1f
  sjmp  lbl_0029
lbl_0026:
  mov   @r0, #0x00
  dec   r0
lbl_0029:
  cjne  r0, #0x1f, lbl_0026
  mov   r0, #0x1f
  sjmp  lbl_0033
lbl_0030:
  mov   @r0, #0x00
  dec   r0
lbl_0033:
  cjne  r0, #0x1f, lbl_0030
  mov   dptr, #0x0001
  mov   r6, dph
  mov   r7, dpl
  mov   dptr, #0x0001
lbl_0040:
  lcall ptr_equal
  jz    lbl_004a
  clr   a
  movx  @dptr, a
  inc   dptr
  sjmp  lbl_0040
lbl_004a:
  mov   dptr, #0x0001
  mov   r0, dpl
  mov   dptr, #0x0001
  mov   r1, dpl
lbl_0054:
  mov   a, r0
  clr   c
  subb  a, r1
  jnc   lbl_005e
  mov   @r0, #0x00
  inc   r0
  sjmp  lbl_0054
lbl_005e:
  mov   dptr, #cdat_00e9
  lcall data_copy
  mov   dptr, #cdat_00ed
  lcall data_copy
  mov   dptr, #cdat_00f1
  lcall data_copy
  mov   dptr, #cdat_00f5
  lcall xdata_copy
  mov   dptr, #cdat_00fb
  lcall xdata_copy
  mov   dptr, #cdat_0101
  lcall xdata_copy
lbl_0082:
  mov   psw, #0x00
  lcall fcn_042f
  ljmp  loop_forever

; return 0 if (r7 == dpl) && (r6 == dph)
; else return non-zero
ptr_equal: ; 008b
  mov   a, r7
  xrl   a, dpl
  jnz   lbl_0093
  mov   a, r6
  xrl   a, dph
lbl_0093:
  ret

; memcpy-like
; input: dptr (code) points to array of 3 pointers
;   uint8 dest_start (data)
;   uint8 dest_end (data)
;   uint16 source (code)
data_copy: ; 0094
  clr   a
  movc  a, @a+dptr
  mov   r0, a     ; r0 = dest_start
  mov   a, #0x01
  movc  a, @a+dptr
  mov   r1, a     ; r1 = dest_end
  mov   a, #0x02
  movc  a, @a+dptr
  mov   r6, a
  mov   a, #0x03
  movc  a, @a+dptr
  mov   dpl, a
  mov   dph, r6    ; dptr = source
lbl_00a6:
  mov   a, r0
  xrl   a, r1
  jnz   lbl_00ab   ; if r0 == r1, return
  ret
lbl_00ab:
  clr   a
  movc  a, @a+dptr ; a = *src
  mov   @r0, a     ; *dst = a
  inc   dptr       ; src++
  inc   r0         ; dst++
  sjmp  lbl_00a6

; memcpy-like
; input: dptr (code) points to array of 3 16-bit pointers
;   ptr[0] = dest (xdata)
;   ptr[1] = source_end (code)
;   ptr[2] = source_start (code)
xdata_copy:
  clr   a
  movc  a, @a+dptr
  mov   r4, a       ; r4 = dest.l
  mov   a, #0x01
  movc  a, @a+dptr
  mov   r5, a       ; r5 = dest.h
  mov   a, #0x02
  movc  a, @a+dptr
  mov   r6, a       ; r6 = source_end.l
  mov   a, #0x03
  movc  a, @a+dptr
  mov   r7, a       ; r7 = source_end.h
  mov   a, #0x04
  movc  a, @a+dptr
  mov   r0, a
  mov   a, #0x05
  movc  a, @a+dptr
  mov   dpl, a
  mov   dph, r0     ; dptr = source_start
lbl_00cc:
  lcall ptr_equal
  jnz   lbl_00d2  ; if source == source_end, return
  ret
lbl_00d2:
  clr   a
  movc  a, @a+dptr ; a = *src
  inc   dptr       ; dptr++
  mov   r0, dph
  mov   r1, dpl    ; r0, r1 = dptr (src += 1)
  mov   dph, r4
  mov   dpl, r5
  movx  @dptr, a   ; *dest = a
  inc   dptr
  mov   r4, dph
  mov   r5, dpl
  mov   dph, r0
  mov   dpl, r1    ; dptr = r0, r1
  sjmp  lbl_00cc

cdat_00e9:
  .byte dat_20_start, dat_20_end
  .word cdat_027e
cdat_00ed:
  .byte dat_20_start, dat_20_end
  .word cdat_027e
cdat_00f1:
  .byte data_start, data_end
  .word cdat_027e
cdat_00f5:
  .word xdat_0001, cdat_0285_start, cdat_0285_end
cdat_00fb:
  .word xdat_0001, cdat_0285_start, cdat_0285_end
cdat_0101:
  .word xdat_0001, cdat_02c9_start, cdat_02c9_end

loop_forever: ; 0107
  sjmp  loop_forever

; jump table lookup
; dptr: points to jump table
;   format: u16 jump_addr, u8 value
; a: value to compare
exti_isr_jmp_table_lookup: ; 0109
  pop   dph
  pop   dpl
  mov   b, a
lbl_010f:
  clr   a
  movc  a, @a+dptr
  jnz   lbl_011c
  mov   a, #0x01
  movc  a, @a+dptr
  jnz   lbl_011c
  inc   dptr
  inc   dptr
  sjmp  lbl_0128
lbl_011c:
  mov   a, #0x02
  movc  a, @a+dptr
  xrl   a, b
  jz    lbl_0128
  inc   dptr
  inc   dptr
  inc   dptr
  sjmp  lbl_010f
lbl_0128:
  mov   a, #0x01
  movc  a, @a+dptr
  push  acc
  clr   a
  movc  a, @a+dptr
  push  acc
  ret
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

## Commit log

2021-01-22 Add USB, I2C comments and label data, xdata, cdata
    * Comment ISRs and some USB, I2C routines
    * Label some data, xdata, and constant data
2021-01-23 Document i2c_write_eeprom and add missing labels
    [ti_graph_link_silver.asm]
2021-03-08 Add KiCad schematics for "A" and "B" Silver Link cables
    * Add notes on "A" Silver Link based on Cypress CY7C64013
    * Add KiCad schematic for "A" and "B" Silver Link cables
    [ti_silver_link_a.sch, ti_silver_link_b.sch]
2021-03-08 Attach Rev1 shematics as PDF and include images in README
2021-03-08 Decode USB device descriptor
2021-03-14 Add csv2bin.py to convert Saleae Logic I2C CSV to binary
2023-07-03 Add KiCad schematic for "okrayo" breadboard Silver Link cable
    - Add schematic for okrayo's breadboard edition of the "B" Silver Link
    - Update README with breadboard schematic information
    [ti_silver_link_okrayo_breadboard.kicad_sch]
2023-07-09 Convert Graph Link "A" and "B" schematics to Kicad 7 format
    [ti_silver_link_a.kicad_sch, ti_silver_link_a.sch, ti_silver_link_b.kicad_sch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]
2023-07-09 Correct "B" and "okrayo" PUR resistor connection to D+
    Rev 1 schematic incorrectly identified PUR resistor connection to D- and
    had the series resistors for D+/D- (R8/R9) swapped. Move PUR resistor R4
    to D+ and use R8 for D+ and R9 for D-.
    [ti_silver_link_b.kicad_sch, ti_silver_link_okrayo_breadboard.kicad_sch]
2023-07-09 Add no-stuff C8 and C11 on "B" Schematic
    [ti_silver_link_b.kicad_sch]
2023-07-09 Generate updated PDF schematics for rev2 "B" and "okrayo" breadboard
2023-07-09 Update "B" and "okrayo" schematics in README.md
2023-07-16 Update symbol and datasheet for CH461FGP on "B" schematic
    [ti_silver_link_b.kicad_sch]
2023-07-23 Breadboard: move R4 D+ pullup resistor after R8 series resistor
    TUSB3410 datasheet lists 1.5kΩ PUR pullup resistor after the D+ series
    resistor. The USB Graph Link "B" schematic has this before the series
    resistor. Correct "okrayo" breadboard schematic with this change to
    align it with the datasheet.
    [ti_silver_link_okrayo_breadboard.kicad_sch]
2023-08-06 Add KiCad schematic TI-Graph Link serial black cable
    * Add KiCad schematic for black TI-Graph Link cable based on LM339
    * Update README with black and grey serial TI-Graph Links
    [ti_graph_link_serial_black.kicad_sch]
2023-08-21 Fix bcdDevice comment from 4.08 to 2.08
    [ti_graph_link_silver.asm]
2024-02-25 Convert all +3.3V nest to +3V3 in TI Silver Link "B" schematic
    Addresses issue #3
    USB Silver Link "B" schematic had a mix of +3.3V and +3V3 nets.
    [ti_silver_link_b.kicad_sch, ti_silver_link_okrayo_breadboard.kicad_sch]
2024-02-25 Move I2C and TEST pullups near their respective devices
    - Move I2C pullups near EEPROM
    - Move TEST pullups near TUSB3410
    [ti_silver_link_b.kicad_sch, ti_silver_link_okrayo_breadboard.kicad_sch]
2024-02-25 TI USB Graph Link "B" and Breadboard rev 3
    Bump revision and date for TI USB Graph Link "B" and breadboard
    [ti_silver_link_b.kicad_sch, ti_silver_link_okrayo_breadboard.kicad_sch]
2025-07-07 Add KiCad schematic TI-Graph Link serial gray cable
    * Add KiCad schematic for gray TI-Graph Link cable based on PIC16C54
    * Update README
    [ti_graph_link_serial_gray.kicad_sch]
2025-07-07 Update TI Graph Link serial gray pictures
    Add photos with
    1. disassembled serial gray link cable
    2. gray link cable PCB with annotation
2025-07-10 Initial commit of TI Graph-Link serial gray assembly
